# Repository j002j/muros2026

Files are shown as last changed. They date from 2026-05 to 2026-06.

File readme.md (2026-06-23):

# Ocean Oxygen Physicalisation

<p align="center">
  Titelbild
</p>

An interactive physical computing installation that visualises dissolved oxygen patterns in ocean Oxygen Minimum Zones (OMZs) through light, depth and material.

The installation uses an ESP32, a 289 LED NeoPixel matrix, five physical buttons and five stacked milky acrylic layers. Instead of showing the dataset on a screen, oxygen values are translated into a spatial light object. Each acrylic layer represents a depth zone, while each button selects a different year.

The project focuses on two ocean regions:

- **Peru-Chile Oxygen Minimum Zone**
- **Eastern Tropical Atlantic Oxygen Minimum Zone**

Both regions are used as case studies for communicating ocean deoxygenation, marine stress and the fragile visual language of oxygen loss.

---

## Project Idea

Oxygen Minimum Zones are ocean regions where dissolved oxygen is very low. They are natural features of the ocean, but ocean warming and climate-driven changes can intensify deoxygenation and affect marine ecosystems.

This installation turns that abstract phenomenon into a physical experience.

The visual system follows a **“Bleached Ocean” / “Cyan Stress”** aesthetic:

- deep blue = oxygen-rich / stable
- cyan = stressed transition state
- pale bleached tones = oxygen-depleted / fragile
- layered acrylic = ocean depth
- soft diffusion = underwater atmosphere

The goal is not to create a precise scientific chart, but a data-based physical interpretation that makes oxygen loss emotionally readable.

---

## Interaction

The installation has five physical buttons.

| Button | Year |
|---|---|
| Button 1 | 2004 |
| Button 2 | 2009 |
| Button 3 | 2014 |
| Button 4 | 2019 |
| Button 5 | 2024 |

Pressing a button changes the displayed year.  
The LED matrix fades into the selected data state instead of switching abruptly.

Additional interaction modes:

| Interaction | Function |
|---|---|
| Short button press | Select year |
| Hold Button 2 | Switch installation on/off |
| Hold Button 5 | Start/stop Auto-Play |
| Idle mode | Subtle ocean breathing |
| Auto-Play | Automatically moves through the years |

The interaction is intentionally simple: the object should feel like a calm ocean artefact, not like a technical control panel.

---

## Visual Mapping

The installation maps oxygen conditions to a custom colour palette.

```python
O2_PALETTE = [
    (140, 135, 110), # Step 0: bleached / oxygen-depleted
    (0, 255, 180),   # Step 1: stressed cyan
    (0, 100, 200),   # Step 2: cyan-blue
    (0, 0, 120),     # Step 3: dark royal blue
    (0, 0, 200),     # Step 4: saturated blue
    (0, 0, 255)      # Step 5: deep ocean blue
]
```

The mapping is intentionally atmospheric, but still data-based.
It is designed to make later years appear more stressed, pale and fragile where oxygen decreases.

## Regions
Peru-Chile OMZ

The Peru-Chile OMZ is used as one of the main visual scenarios.
It represents a strong oxygen minimum zone in the eastern tropical Pacific and is especially suitable for a dramatic visual story because oxygen depletion can be spatially intense.

In the installation, this region is mapped across five depth layers and five selected years.

Eastern Tropical Atlantic OMZ

The Eastern Tropical Atlantic region is included as a second ocean case study.
It allows comparison between different oxygen minimum zone dynamics and helps communicate that ocean deoxygenation is not a single local event, but part of a broader marine pattern.

The code can be adapted to switch between the two regional mappings.

## Hardware

Main components:

Component	Description
Microcontroller	ESP32
LEDs	NeoPixel / WS2812 matrix
LED count	289 LEDs
Interaction	5 physical push buttons
Material	5 milky acrylic layers
Power	External 5V LED power supply
Pin Configuration
Component	ESP32 Pin
LED data pin	GPIO 13
Button 1	GPIO 19
Button 2	GPIO 18
Button 3	GPIO 5
Button 4	GPIO 17
Button 5	GPIO 16

The buttons use internal pull-up resistors and are active-low.
This means that pressing a button connects the GPIO pin to GND.

## Software

The installation is written in MicroPython and runs directly on the ESP32.

Recommended editor:

Thonny

Main libraries:

```python
from machine import Pin
from neopixel import NeoPixel
from time import sleep_ms, ticks_ms, ticks_diff
import math
```
MicroPython usually includes NeoPixel support by default.
If needed, the NeoPixel package can be installed through Thonny’s package manager.

## Inspiration

Brainstorming and visual research:
https://www.figma.com/board/NZpllUfHZYUcmpAbdbsu1X/Morus2026

## Sources and References

Scientific and data references:

NOAA Ocean Exploration
https://oceanexplorer.noaa.gov/ocean-fact/omz/

NOAA National Centers for Environmental Information, World Ocean Atlas
https://www.ncei.noaa.gov/products/world-ocean-atlas

World Ocean Atlas 2023 Data
https://www.ncei.noaa.gov/access/world-ocean-atlas-2023/

Copernicus Marine, Global Ocean Biogeochemistry Hindcast
https://data.marine.copernicus.eu/product/GLOBAL_MULTIYEAR_BGC_001_029/description

Karstensen et al., Oxygen minimum zones in the eastern tropical Atlantic and Pacific oceans
https://oceanrep.geomar.de/7187/

Technical references:

MicroPython
https://micropython.org/

Thonny Python IDE
https://thonny.org/

Adafruit NeoPixel Überguide
https://learn.adafruit.com/adafruit-neopixel-uberguide

## Credits

Created as part of a data physicalisation project on ocean oxygen decline and marine stress.

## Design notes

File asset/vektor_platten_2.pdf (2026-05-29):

Durchmesser 184

Material: Plexiglass 2mm dick

Bearbeitung mit Laserzuschnitt

Toleranz: ±0,3 mm ?????

Bohrung: Keine

Alle alle 3 mm

Erste Ebene

- 184 cm durchmesser
- Diese Schicht dient als Diffusor, damit die LEDs dadrunter weich gemahct werden.
- Es soll leich milchig sein (damit die LEDs under der platte sanfter durchleuchten)
- Um das milchige zu erhlaten, die oberfläche anrauen oder so

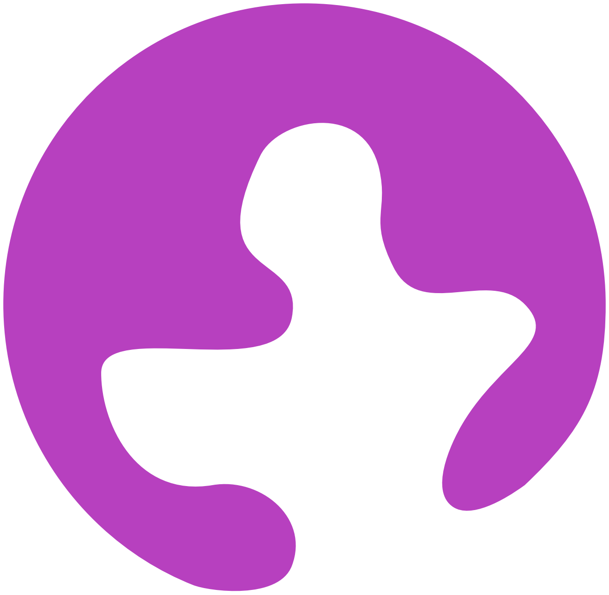
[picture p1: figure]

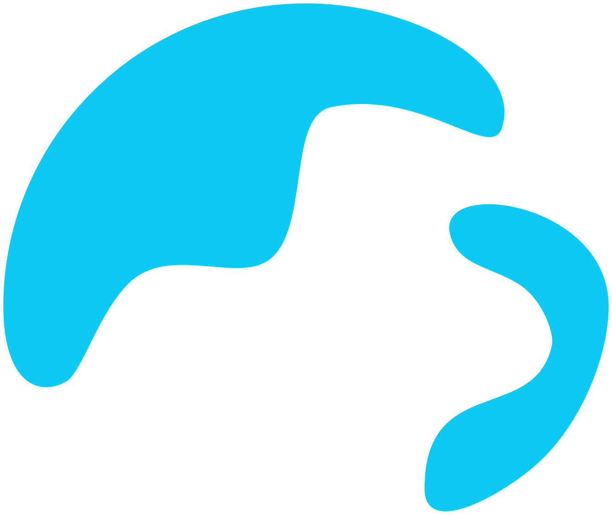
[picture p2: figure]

Die Platten sollen am Ende überinandergelagert werden.

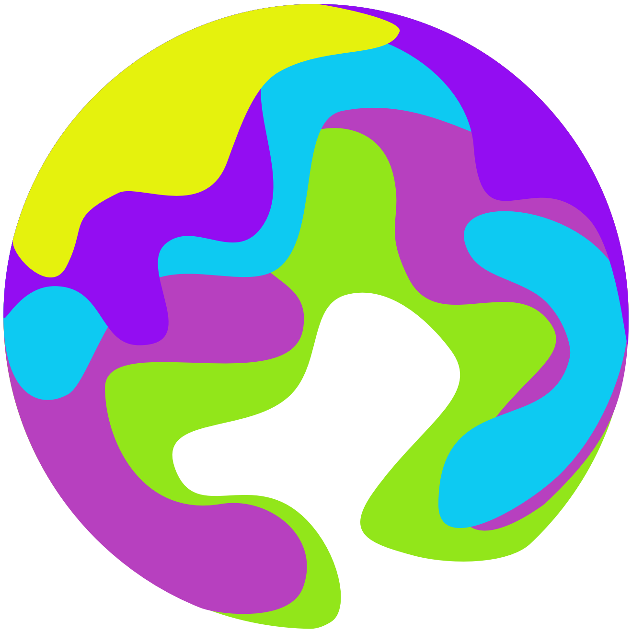
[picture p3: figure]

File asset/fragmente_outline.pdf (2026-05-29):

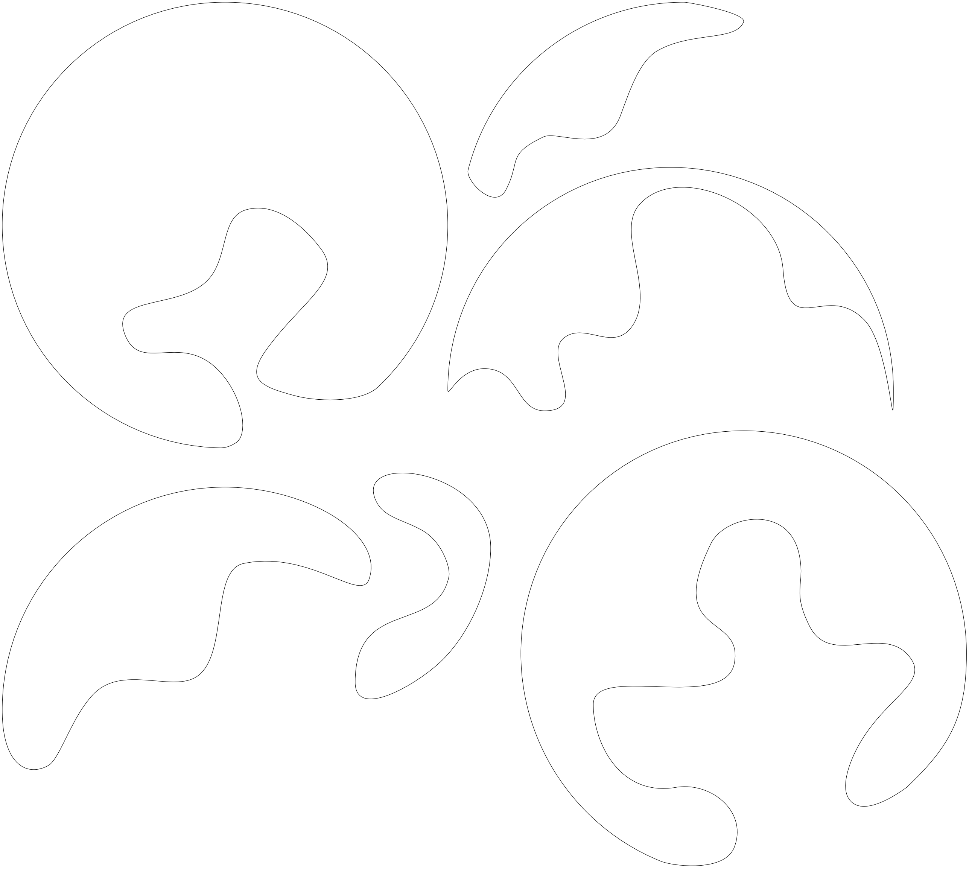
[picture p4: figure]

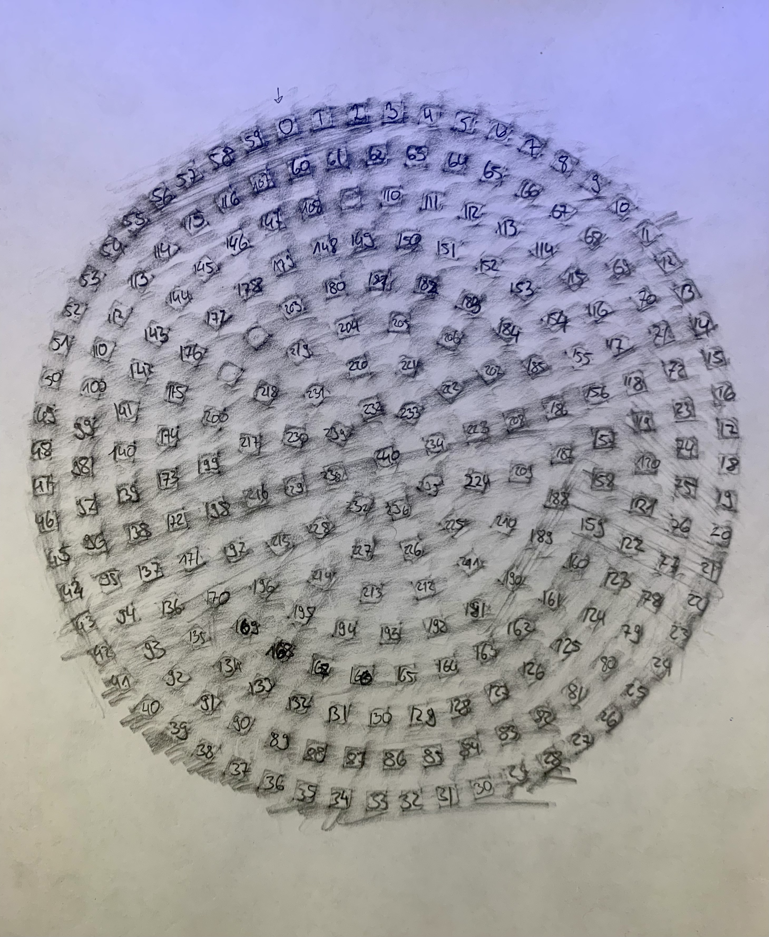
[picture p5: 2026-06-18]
asset/led_ numbered.jpeg

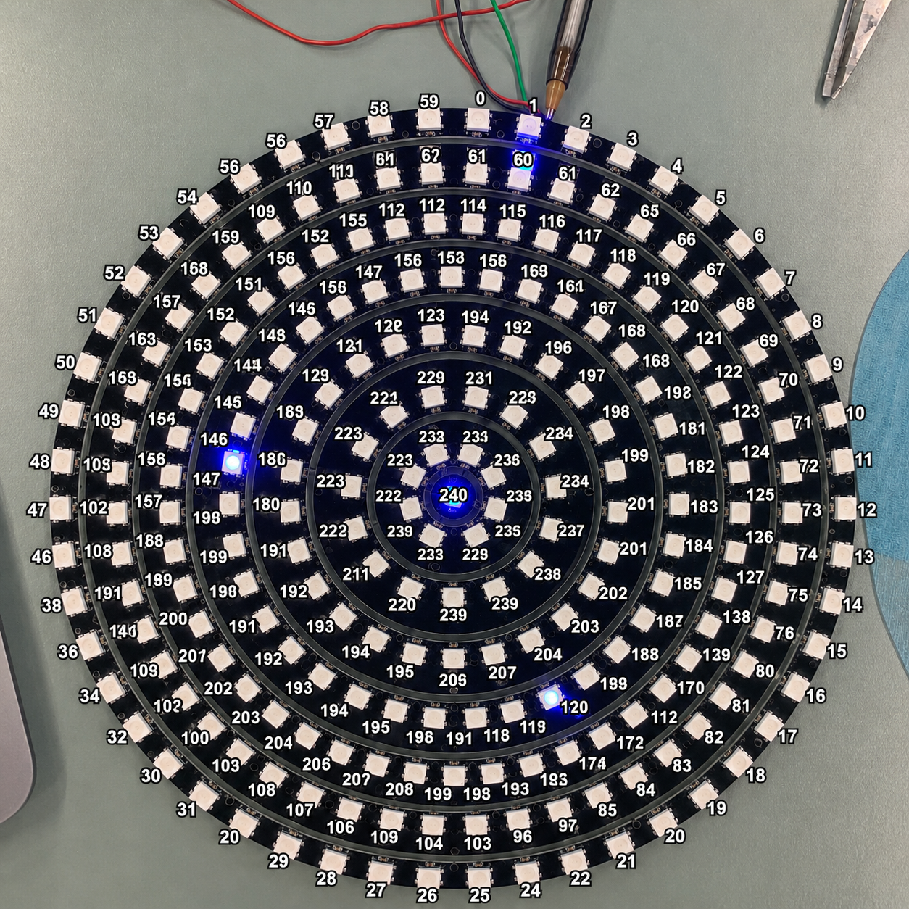
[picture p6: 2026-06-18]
asset/led_falsely_numberd.png

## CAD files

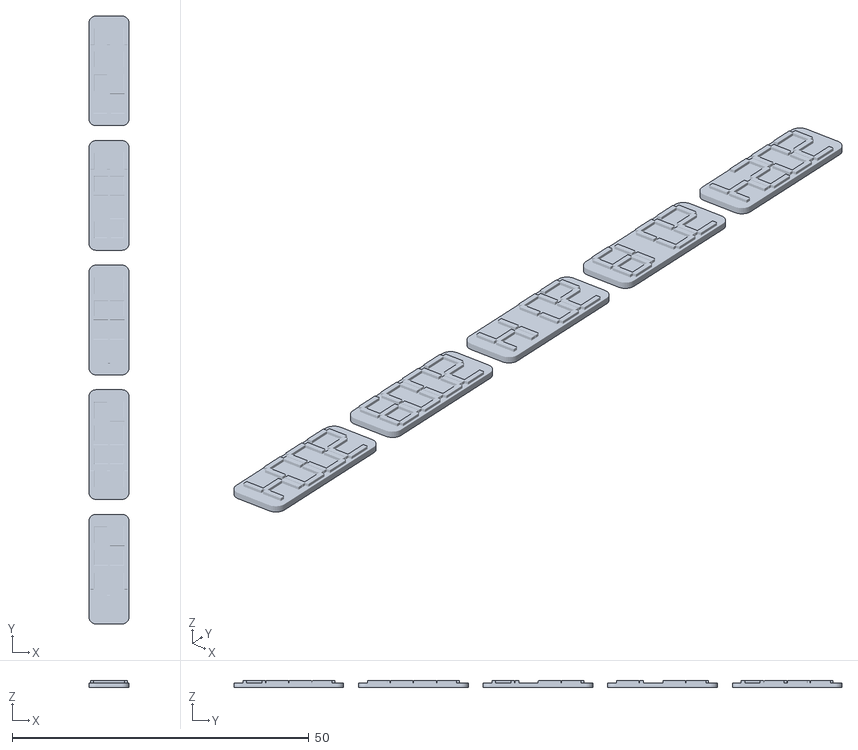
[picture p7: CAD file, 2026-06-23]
finalversion/jahresschilder.stl
6.80 x 102.5 x 1.10

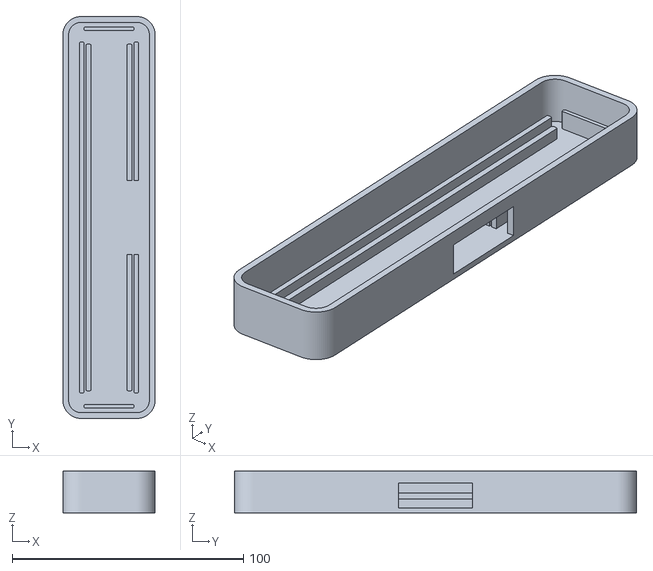
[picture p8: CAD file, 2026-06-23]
finalversion/unterteil.stl
40.0 x 174.0 x 18.0

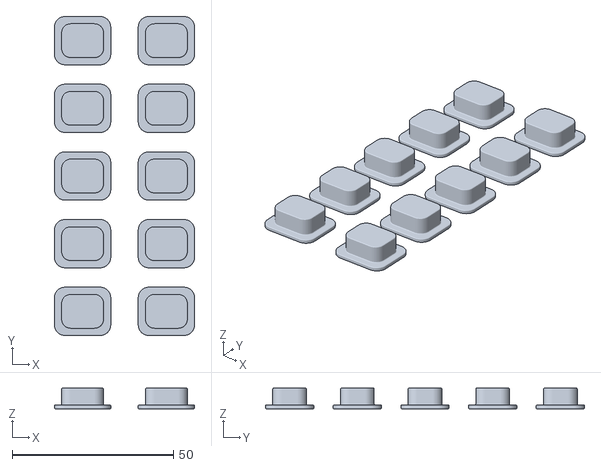
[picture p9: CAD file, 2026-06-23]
finalversion/knopfvarianten.stl
43.5 x 99.0 x 6.40

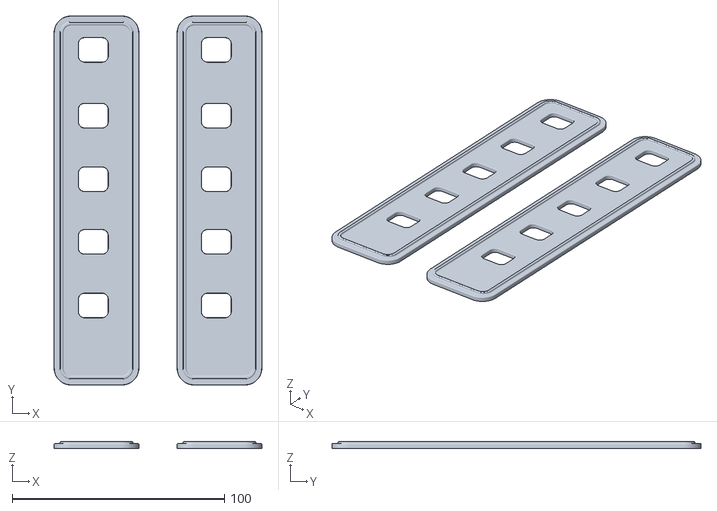
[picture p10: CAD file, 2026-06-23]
finalversion/deckel.stl
98.0 x 174.0 x 3.40

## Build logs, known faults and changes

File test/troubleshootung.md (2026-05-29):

```markdown
# Problembehebung: ESP32 "Device is busy" & Thonny Absturz auf macOS

## 1. Das ursprüngliche Problem
Beim Versuch, den ESP32 mit der IDE **Thonny** auf dem Mac anzusteuern, erschien folgende Fehlermeldung:
> *Device is busy or does not respond. Your options: wait until it completes current work; use Ctrl+C to interrupt current work...*

Zusätzlich stürzte das eingebaute MicroPython-Flash-Werkzeug von Thonny mit einem Python-Fehler ab:
`AttributeError: 'NoneType' object has no attribute 'port'`

### Ursachen-Analyse:
1. **Kein MicroPython auf dem Board:** Der ESP32 wurde im Werkszustand geliefert (meistens mit C++ Firmware) und verstand Thonny nicht.
2. **Thonny-Software-Bug:** Ein bekannter Fehler im Zusammenspiel zwischen Thonny, macOS und Python 3.14 verhinderte, dass Thonny den USB-Port korrekt zuordnen und die Firmware flashen konnte.
3. **Anaconda-Konflikt:** Auf dem Mac ist Anaconda installiert, weshalb Standard-Terminalbefehle wie `pip` oder `python3` in die Anaconda-Umgebung umgeleitet wurden, wo das Flash-Werkzeug (`esptool`) fehlte.

---

## 2. Der Lösungsansatz
Da die grafische Oberfläche von Thonny blockiert war, wurde die Installation von MicroPython komplett an Thonny vorbei über das native **macOS-Terminal** durchgeführt. Dabei wurde das offizielle Espressif-Flash-Werkzeug (`esptool`) direkt über den spezifischen Anaconda-Pfad installiert und ausgeführt.

---

## 3. Konkreter Lösungsweg (Schritt für Schritt)

### Schritt 1: Thonny schließen
Thonny vollständig beenden (`Cmd + Q`), damit die USB-Verbindung zum ESP32 nicht blockiert wird.

### Schritt 2: Den USB-Port des ESP32 ermitteln
Das macOS-Terminal öffnen und alle aktiven USB-Schnittstellen auflisten:
```bash
ls /dev/cu.*

```

*Ergebnis:* Der korrekte Port wurde als **`/dev/cu.usbserial-1410`** identifiziert (da der verbaute CP2102N-Chip korrekt vom Mac erkannt wurde).

### Schritt 3: Flash-Tool in der Anaconda-Umgebung installieren

Da Anaconda als Standard-Python genutzt wird, musste das Tool über den absoluten Anaconda-Pfad installiert werden:

```bash
/opt/anaconda3/bin/pip install esptool

```

### Schritt 4: Alten Flash-Speicher des ESP32 löschen

Um Reste alter Firmware zu entfernen, wurde der Speicher geleert:

```bash
/opt/anaconda3/bin/python3 -m esptool --port /dev/cu.usbserial-1410 erase_flash

```

*Hinweis:* Sobald im Terminal `Connecting...` erscheint, muss der **BOOT-Knopf** auf dem ESP32 gedrückt gehalten werden.

### Schritt 5: MicroPython-Firmware aufspielen

Die aktuelle MicroPython `.bin`-Datei (z. B. `v1.28.0.bin`) von der offiziellen Website herunterladen. Den Befehl im Terminal vorbereiten, ein Leerzeichen tippen und die Datei per Drag & Drop in das Terminal ziehen:

```bash
/opt/anaconda3/bin/python3 -m esptool --chip esp32 --port /dev/cu.usbserial-1410 write_flash -z 0x1000 /Pfad/zur/heruntergeladenen/datei.bin

```

*Hinweis:* Auch hier bei `Connecting...` den **BOOT-Knopf** am ESP32 gedrückt halten, bis der Upload startet (Prozentanzeige läuft bis 100%).

---

## 4. Ergebnis & Nächste Schritte

Nachdem `Hash of data verified.` im Terminal stand, wurde der ESP32 erfolgreich geflasht.

**Vorgehen jetzt in Thonny:**

1. ESP32 einmal kurz vom USB-Kabel trennen und wieder anstecken.
2. Thonny öffnen.
3. Unter *Werkzeuge -> Optionen -> Interpreter* als Gerät **MicroPython (ESP32)** und als Port explizit **`/dev/cu.usbserial-1410`** auswählen.
4. Den roten **Stop-Button** in Thonny drücken.
5. In der Shell erscheinen die drei Pfeile (`>>>`) – der ESP32 ist nun einsatzbereit für die LED-Steuerung.

## Wenn der Fehler nochmal vorkommt
```bash
ls /dev/cu.*
```

die ausgaben oben in das XXX unten einsetzten:

```bash
/opt/anaconda3/bin/python3 -m esptool --port /dev/cu.XXX erase_flash
```
Da die .bin-Datei wahrscheinlich noch in deinem Download-Ordner ist, musst diese nur wieder reingeschoben werden. Befehl eintippen, Leerzeichen, Datei per Drag & Drop reinziehen (und wieder den BOOT-Knopf drücken):

```bash
/opt/anaconda3/bin/python3 -m esptool --chip esp32 --port /dev/cu.usbserial-1410 write_flash -z 0x1000 /Pfad/zur/heruntergeladenen/datei.bin
```

```

```

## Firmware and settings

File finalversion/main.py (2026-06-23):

# main.py
# ESP32 + MicroPython + NeoPixel/WS2812
# Ocean O2 Data Physicalisation
# Edition: "Cyan Stress" + Flowy Auto-Play & Subtles Feedback

from machine import Pin
from neopixel import NeoPixel
from time import sleep_ms, ticks_ms, ticks_diff
import math

# =======================================================
# 1. HARDWARE-KONFIGURATION
# =======================================================

LED_PIN = 13
NUM_LEDS = 289  # Volle Matrix

BUTTON_PINS = [19, 18, 5, 17, 16]
BUTTON_ACTIVE_VALUE = 0
BUTTON_PULL = Pin.PULL_UP
BRIGHTNESS = 1.0

# =======================================================
# 2. ZONEN & AUTO-FILL
# =======================================================

BOTTOM_LAYER = [
    28, 29, 30, 31, 32, 84, 85, 86, 129, 130, 165, 166, 167, 168, 169,
    181, 191, 192, 193, 194, 195, 210, 211, 212, 213, 214, 224, 225,
    226, 227, 235, 236
]

ZONE_RANGES = [
    [14, 15, 26, 27, 33, 34, 82, 83, 86, 127, 128, 130, 121, 158, 159, 160, 161, 162, 163, 164, 134, 135, 136, 137, 138, 170, 171, 197, 196, 215, 228, 237, 240, 234, 209, 223, 222, 233, 232, 224, 205, 206, 181, 182],
    [122, 131, 132, 133, 87, 88, 89, 90, 91, 92, 93, 94, 95, 35, 36, 37, 38, 39, 40, 41, 42, 43, 44, 45, 138, 198, 216, 229, 238, 217, 230, 239, 150, 151, 152, 153, 154, 184, 183, 185, 207, 208, 187, 172, 117, 204],
    [126, 162, 231, 220, 204, 180, 181, 96, 97, 98, 156, 147, 139, 140, 218, 200, 149, 148, 109, 110, 111, 112, 113, 114, 81, 80, 79, 77, 76, 75, 74, 73, 120, 119, 118, 20, 19, 18],
    [19, 18, 17, 16, 15, 14, 13, 12, 11, 10, 69, 70, 71, 72, 115, 116, 65, 66, 67, 68, 173, 174, 175, 176, 141, 142, 143, 99, 48, 49, 219, 203],
    [177, 178, 179, 144, 145, 146, 147, 105, 61, 60, 0, 1, 2, 3, 4, 5, 50, 51, 52, 53, 54, 56, 57, 58, 59, 100, 101, 102, 103, 104, 106, 107, 108]
]

mapped_leds = set(BOTTOM_LAYER)
for layer in ZONE_RANGES:
    mapped_leds.update(layer)
unmapped_leds = [i for i in range(NUM_LEDS) if i not in mapped_leds]
BOTTOM_LAYER.extend(unmapped_leds)

# =======================================================
# 3. DATA MAPPING 
# =======================================================

YEARS = [2004, 2009, 2014, 2019, 2024]

AMBIENT_COLOR = (0, 0, 8)       
BOTTOM_COLOR = (0, 0, 15)       

O2_PALETTE = [
    (140, 135, 110), # Step 0: Knochenweiß (Tot)
    (0, 255, 180),   # Step 1: Grelles Cyan (Warnung)
    (0, 100, 200),   # Step 2: Cyan-Blau 
    (0, 0, 120),     # Step 3: Dunkles Royalblau 
    (0, 0, 200),     # Step 4: Sattes Royalblau
    (0, 0, 255)      # Step 5: Pures, tiefes Royalblau 
]

OMZ_DATA_STEPS = [
    [5, 4, 1, 4, 5], # 2004
    [5, 3, 0, 3, 5], # 2009
    [4, 1, 0, 1, 4], # 2014
    [3, 0, 0, 0, 2], # 2019
    [1, 0, 0, 0, 2], # 2024
]

LAYER_COMPENSATION = [1.0, 1.0, 1.0, 1.0, 1.0]

# =======================================================
# 4. GLOBALE STATUS-VARIABLEN FÜR ANIMATIONEN
# =======================================================

base_pixels = [(0,0,0)] * NUM_LEDS
is_dead_pixel = [False] * NUM_LEDS  
current_year_index = 0

# =======================================================
# 5. SETUP & HELPERS
# =======================================================

np = NeoPixel(Pin(LED_PIN, Pin.OUT), NUM_LEDS)
buttons = [Pin(pin_number, Pin.IN, BUTTON_PULL) for pin_number in BUTTON_PINS]

def scale_color(color, comp_factor=1.0):
    r, g, b = color
    return (int(r * BRIGHTNESS * comp_factor), int(g * BRIGHTNESS * comp_factor), int(b * BRIGHTNESS * comp_factor))

def clear_leds():
    for i in range(NUM_LEDS):
        np[i] = (0, 0, 0)
    np.write()

def build_target_data(year_index):
    t_pixels = [scale_color(AMBIENT_COLOR)] * NUM_LEDS
    t_dead = [False] * NUM_LEDS

    bottom_scaled = scale_color(BOTTOM_COLOR)
    for led_idx in BOTTOM_LAYER:
        if 0 <= led_idx < NUM_LEDS:
            t_pixels[led_idx] = bottom_scaled

    for layer_index in range(5):
        step = OMZ_DATA_STEPS[year_index][layer_index]
        comp = LAYER_COMPENSATION[layer_index]
        layer_color = scale_color(O2_PALETTE[step], comp_factor=comp)
        
        is_dead = (step == 0) 

        for led_idx in ZONE_RANGES[layer_index]:
            if 0 <= led_idx < NUM_LEDS:
                t_pixels[led_idx] = layer_color
                t_dead[led_idx] = is_dead

    return t_pixels, t_dead

# =======================================================
# 6. GIMMICKS: FEEDBACK + BREATHING
# =======================================================

FEEDBACK_EDGE_COLOR = (0, 28, 55)  
FEEDBACK_EDGE_MS = 55            
FEEDBACK_EDGE_BLEND = 0.55        


# Atmen: .
BREATH_SPEED = 1400
BREATH_BASE = 0.97
BREATH_AMOUNT = 0.03

# Fade-Geschwindigkeiten:
BUTTON_FADE_STEPS = 18
BUTTON_FADE_DELAY_MS = 12

AUTOPLAY_FADE_STEPS = 64
AUTOPLAY_FADE_DELAY_MS = 18

POWER_FADE_STEPS = 18
POWER_FADE_DELAY_MS = 10

def get_data_leds():
    """
    Nur die 5 echten Daten-Zonen.
    Bottom, Rand und Auto-Fill gehören NICHT dazu.
    """
    data = set()

    for layer in ZONE_RANGES:
        for led in layer:
            if 0 <= led < NUM_LEDS:
                data.add(led)

    return data


DATA_LEDS = get_data_leds()
FEEDBACK_LEDS = [i for i in range(NUM_LEDS) if i not in DATA_LEDS]


def feedback_kick(restore_after=True):
    """
    Data-neutrales Button-Feedback:
    Nur Rand-/Nicht-Daten-LEDs bekommen kurz einen kühlen Impuls.
    Die eigentlichen Datenzonen bleiben unverändert.
    """
    start_pixels = [np[i] for i in range(NUM_LEDS)]
    fc = scale_color(FEEDBACK_EDGE_COLOR)

    for led in FEEDBACK_LEDS:
        r, g, b = start_pixels[led]

        np[led] = (
            int(r * (1 - FEEDBACK_EDGE_BLEND) + fc[0] * FEEDBACK_EDGE_BLEND),
            int(g * (1 - FEEDBACK_EDGE_BLEND) + fc[1] * FEEDBACK_EDGE_BLEND),
            int(b * (1 - FEEDBACK_EDGE_BLEND) + fc[2] * FEEDBACK_EDGE_BLEND)
        )

    np.write()
    sleep_ms(FEEDBACK_EDGE_MS)

    if restore_after:
        for led in FEEDBACK_LEDS:
            np[led] = start_pixels[led]

        np.write()

def get_breath_factor():
    return BREATH_BASE + BREATH_AMOUNT * math.sin(ticks_ms() / BREATH_SPEED)


def apply_breath_to_color(color, factor):
    r, g, b = color
    return (
        int(r * factor),
        int(g * factor),
        int(b * factor)
    ) 

def render_ocean_breath():
    """
    subtiler Ocean Breath.
    Nur die echten Datenlayer atmen.
    Boden, Rand und Auto-Fill bleiben konstant.
    """
    factor = get_breath_factor()

    for i in range(NUM_LEDS):
        np[i] = base_pixels[i]

    for i in DATA_LEDS:
        r, g, b = base_pixels[i]
        np[i] = (
            int(r * factor),
            int(g * factor),
            int(b * factor)
        )

    np.write()


# =======================================================
# 7. DISPLAY & FADE LOGIC
# =======================================================

def show_year(year_index):
    global current_year_index, base_pixels, is_dead_pixel

    current_year_index = year_index
    base_pixels, is_dead_pixel = build_target_data(year_index)

    for i in range(NUM_LEDS):
        np[i] = base_pixels[i]

    np.write()

    print("AKTIV:", YEARS[year_index])
    for layer_index in range(5):
        step = OMZ_DATA_STEPS[year_index][layer_index]
        comp = LAYER_COMPENSATION[layer_index]
        rgb = scale_color(O2_PALETTE[step], comp)
        print("  Layer", layer_index + 1, "| Step", step, "| RGB", rgb)


def fade_to_year(year_index, steps=BUTTON_FADE_STEPS, delay_ms=BUTTON_FADE_DELAY_MS):
    """
    Weicher Fade zum Zieljahr.
    Buttondruck = zügig.
    Auto-Play = langsamer über andere Parameter.
    """
    global current_year_index, base_pixels, is_dead_pixel

    start_pixels = [np[i] for i in range(NUM_LEDS)]
    target_pixels, target_dead = build_target_data(year_index)

    for step in range(1, steps + 1):
        t = step / steps

        t = t * t * (3 - 2 * t)

        # Zielbild schon in der aktuellen Breath-Helligkeit berechnen
        breath_factor = get_breath_factor()

        for i in range(NUM_LEDS):
            sr, sg, sb = start_pixels[i]

            tr, tg, tb = apply_breath_to_color(target_pixels[i], breath_factor)

            np[i] = (
                int(sr + (tr - sr) * t),
                int(sg + (tg - sg) * t),
                int(sb + (tb - sb) * t)
            )

        np.write()
        sleep_ms(delay_ms)

    current_year_index = year_index
    base_pixels = target_pixels
    is_dead_pixel = target_dead

    render_ocean_breath()

    print("GEWECHSELT ZU:", YEARS[year_index])
    for layer_index in range(5):
        step = OMZ_DATA_STEPS[year_index][layer_index]
        comp = LAYER_COMPENSATION[layer_index]
        rgb = scale_color(O2_PALETTE[step], comp)
        print("  Layer", layer_index + 1, "| Step", step, "| RGB", rgb)


def fade_to_black(steps=POWER_FADE_STEPS, delay_ms=POWER_FADE_DELAY_MS):
    """
    Sanftes Ausschalten, ohne den MicroPython-Stack zu killen.
    Der Code läuft weiter, LEDs gehen nur optisch aus.
    """
    global base_pixels, is_dead_pixel

    start_pixels = [np[i] for i in range(NUM_LEDS)]

    for step in range(1, steps + 1):
        t = step / steps
        t = t * t * (3 - 2 * t)

        for i in range(NUM_LEDS):
            sr, sg, sb = start_pixels[i]
            np[i] = (
                int(sr * (1 - t)),
                int(sg * (1 - t)),
                int(sb * (1 - t))
            )

        np.write()
        sleep_ms(delay_ms)

    clear_leds()
    base_pixels = [(0, 0, 0)] * NUM_LEDS
    is_dead_pixel = [False] * NUM_LEDS

# =======================================================
# 8. BUTTON CONTROLS
# =======================================================

def read_buttons():
    for idx, button in enumerate(buttons):
        if button.value() == BUTTON_ACTIVE_VALUE:
            sleep_ms(40) 
            if button.value() == BUTTON_ACTIVE_VALUE:
                return idx
    return None

def wait_until_released(button_index):
    while buttons[button_index].value() == BUTTON_ACTIVE_VALUE:
        sleep_ms(20)

# =======================================================
# 9. START & MAIN LOOP
# =======================================================

clear_leds()
show_year(0)

is_system_on = True
auto_play_active = False

POWER_BUTTON_INDEX = 1       
POWER_HOLD_MS = 2000         

AUTOPLAY_BUTTON_INDEX = 4    
AUTOPLAY_HOLD_MS = 5000         

last_interaction_time = ticks_ms()
last_auto_switch = ticks_ms()

AUTO_PLAY_INTERVAL = 8000
ATTRACT_MODE_DELAY = 120000

print("SYSTEM BEREIT.")
print("Button 2 / 2009 kurz: Jahr 2009.")
print("Button 2 / 2009 halten: AN/AUS.")
print("Button 5 / 2024 halten: Auto-Play AN/AUS.")
print("Breathing: nur Datenlayer, Boden/Rand stabil.")


while True:
    current_time = ticks_ms()
    pressed = read_buttons()

    # ===================================================
    # BUTTON GEDRÜCKT
    # ===================================================
    if pressed is not None:
        press_start = ticks_ms()
        hold_done = False

        # -----------------------------------------------
        # BUTTON 2 HOLD: SYSTEM AN/AUS
        # -----------------------------------------------
        if pressed == POWER_BUTTON_INDEX:
            while buttons[POWER_BUTTON_INDEX].value() == BUTTON_ACTIVE_VALUE:
                held_ms = ticks_diff(ticks_ms(), press_start)

                if is_system_on:
                    render_ocean_breath()

                if held_ms >= POWER_HOLD_MS:
                    is_system_on = not is_system_on
                    auto_play_active = False
                    hold_done = True

                    last_interaction_time = ticks_ms()
                    last_auto_switch = ticks_ms()

                    if is_system_on:
                        print("SYSTEM: ON")
                        show_year(current_year_index)
                        feedback_kick(restore_after=True)
                    else:
                        print("SYSTEM: OFF")
                        feedback_kick(restore_after=True)
                        fade_to_black()

                    # warten, bis Button losgelassen wird
                    while buttons[POWER_BUTTON_INDEX].value() == BUTTON_ACTIVE_VALUE:
                        sleep_ms(20)

                    break

                sleep_ms(20)

            if hold_done:
                continue

        # -----------------------------------------------
        # BUTTON 5 HOLD: AUTO-PLAY AN/AUS
        # -----------------------------------------------
        if pressed == AUTOPLAY_BUTTON_INDEX and is_system_on:
            while buttons[AUTOPLAY_BUTTON_INDEX].value() == BUTTON_ACTIVE_VALUE:
                held_ms = ticks_diff(ticks_ms(), press_start)

                render_ocean_breath()

                if held_ms >= AUTOPLAY_HOLD_MS:
                    auto_play_active = not auto_play_active
                    hold_done = True

                    last_interaction_time = ticks_ms()
                    last_auto_switch = ticks_ms()

                    if auto_play_active:
                        print("AUTO-PLAY: ON")
                    else:
                        print("AUTO-PLAY: OFF")

                    feedback_kick(restore_after=True)

                    while buttons[AUTOPLAY_BUTTON_INDEX].value() == BUTTON_ACTIVE_VALUE:
                        sleep_ms(20)

                    break

                sleep_ms(20)

            if hold_done:
                continue

        # -----------------------------------------------
        # NORMALER KURZER BUTTON-KLICK
        # -----------------------------------------------
        wait_until_released(pressed)

        current_time = ticks_ms()
        last_interaction_time = current_time
        last_auto_switch = current_time

        if not is_system_on:
            continue

        if auto_play_active:
            auto_play_active = False
            print("AUTO-PLAY: OFF durch manuelle Eingabe")

        print("Button erkannt:", pressed + 1, "| Jahr:", YEARS[pressed])

        if pressed != current_year_index:
            feedback_kick(restore_after=True)
            fade_to_year(
                pressed,
                steps=BUTTON_FADE_STEPS,
                delay_ms=BUTTON_FADE_DELAY_MS
            )
        else:
            feedback_kick(restore_after=True)

        last_auto_switch = ticks_ms()

    # ===================================================
    # IDLE / AUTO-PLAY
    # ===================================================
    if is_system_on:
        render_ocean_breath()

        idle_time = ticks_diff(current_time, last_interaction_time)
        attract_mode_active = idle_time > ATTRACT_MODE_DELAY

        if auto_play_active or attract_mode_active:
            if ticks_diff(current_time, last_auto_switch) > AUTO_PLAY_INTERVAL:
                next_year = (current_year_index + 1) % len(YEARS)

                if auto_play_active:
                    print("AUTO-PLAY:", YEARS[next_year])
                else:
                    print("ATTRACT-MODE:", YEARS[next_year])

                fade_to_year(
                    next_year,
                    steps=AUTOPLAY_FADE_STEPS,
                    delay_ms=AUTOPLAY_FADE_DELAY_MS
                )

                last_auto_switch = ticks_ms()

    else:
        sleep_ms(20)

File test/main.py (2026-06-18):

# main.py
# ESP32 + MicroPython + NeoPixel/WS2812
# Ocean O2 Data Physicalisation
# 5 Buttons = 5 Jahre
# 5 Plexiglas-Layer = 5 Tiefenzonen
#
# Neue Version:
# - Layer-Unterschiede werden durch stärkere Farbpalette sichtbar.
# - Jahres-Unterschiede werden durch leichten Year-Tint sichtbar.
# - Bottom-Layer wird zuerst gezeichnet, Datenlayer danach.

from machine import Pin
from neopixel import NeoPixel
from time import sleep_ms

# =======================================================
# 1. HARDWARE-KONFIGURATION
# =======================================================

LED_PIN = 13
NUM_LEDS = 241

# Button-Pins von GND aus nach links:
# Button 1 = 2004
# Button 2 = 2009
# Button 3 = 2014
# Button 4 = 2019
# Button 5 = 2024
BUTTON_PINS = [19, 18, 5, 17, 16]

# Annahme: Button verbindet GPIO mit GND.
# gedrückt = 0, nicht gedrückt = 1
BUTTON_ACTIVE_VALUE = 0
BUTTON_PULL = Pin.PULL_UP

# Globaler Helligkeitsregler:
# 1.0 = volle Werte
# 0.7 = etwas softer
# 0.5 = deutlich weicher
BRIGHTNESS = 0.8

# Fade an/aus
USE_FADE = True

# Bottom-Layer / Basislicht
WEISS = (20, 20, 20)

BOTTOM_LAYER = [ 28, 29, 30, 31, 32, 84, 85, 86, 129, 130, 165, 166, 167, 168, 169, 181, 191, 192, 193, 194, 195, 210, 211, 212, 213, 214, 224, 225, 226, 227, 235, 236 ] # Die verbleibenden 209 Daten-LEDs – jede Zahl existiert exakt 1x!
ZONE_RANGES = [
    # Layer 1: 100-250m (45 LEDs -> Doppelte 126 bereinigt, Lücken geschlossen)
    [14, 15, 26, 27, 33, 34, 82, 83, 121, 123, 124, 125, 127, 128, 134, 135, 136, 137, 138, 158, 159, 160, 161, 162, 163, 164, 170, 171, 182, 186, 196, 197, 199, 205, 206, 209, 215, 221, 222, 223, 228, 232, 233, 234, 237, 240],
    # Layer 2: 250-400m (53 LEDs)
    [35, 36, 37, 38, 39, 40, 41, 42, 43, 44, 45, 87, 88, 89, 90, 91, 92, 93, 94, 95, 117, 122, 131, 132, 133, 150, 151, 152, 153, 154, 155, 172, 183, 184, 185, 187, 188, 189, 190, 198, 201, 202, 203, 204, 207, 208, 216, 217, 229, 230, 231, 238, 239],
    # Layer 3: 400-600m (36 LEDs)
    [18, 19, 20, 21, 22, 23, 24, 25, 73, 74, 75, 76, 77, 79, 80, 81, 96, 97, 98, 109, 110, 111, 112, 113, 114, 118, 119, 120, 126, 139, 140, 148, 149, 156, 180, 200, 218],
    # Layer 4: 600-750m (30 LEDs -> Doppelte Einträge am Ende entfernt)
    [6, 7, 8, 9, 10, 11, 12, 13, 16, 17, 48, 49, 65, 66, 67, 68, 69, 70, 71, 72, 99, 115, 116, 141, 142, 143, 173, 174, 175, 176, 219],
    # Layer 5: 750-900m (45 LEDs)
    [0, 1, 2, 3, 4, 5, 46, 47, 50, 51, 52, 53, 54, 55, 56, 57, 58, 59, 60, 61, 62, 63, 64, 78, 100, 101, 102, 103, 104, 105, 106, 107, 108, 144, 145, 146, 147, 177, 178, 179]
]

# =======================================================
# 2. DATA MAPPING V2
# =======================================================

YEARS = [2004, 2009, 2014, 2019, 2024]
LAYER_LABELS = ['100-250m', '250-400m', '400-600m', '600-750m', '750-900m']

# Eastern Tropical Atlantic | normal
# normal: more O2 = more blue
DATA_COLORS_EASTERN_TROPICAL_ATLANTIC_NORMAL = [
    [(0, 35, 148), (0, 14, 59), (0, 21, 90), (0, 44, 188), (0, 59, 251)],  # 2004
    [(0, 34, 144), (0, 14, 59), (0, 22, 94), (0, 45, 193), (0, 60, 255)],  # 2009
    [(0, 34, 146), (0, 14, 58), (0, 21, 90), (0, 44, 188), (0, 59, 250)],  # 2014
    [(0, 34, 144), (0, 13, 54), (0, 20, 87), (0, 43, 185), (0, 58, 246)],  # 2019
    [(0, 35, 147), (0, 12, 51), (0, 19, 79), (0, 42, 177), (0, 57, 243)],  # 2024
]

# Eastern Tropical Atlantic | inverted
# inverted: less O2 = more blue
DATA_COLORS_EASTERN_TROPICAL_ATLANTIC_INVERTED = [
    [(0, 37, 158), (0, 58, 247), (0, 51, 216), (0, 28, 118), (0, 13, 55)],  # 2004
    [(0, 38, 162), (0, 58, 247), (0, 50, 212), (0, 27, 113), (0, 12, 51)],  # 2009
    [(0, 38, 160), (0, 58, 248), (0, 51, 216), (0, 28, 118), (0, 13, 56)],  # 2014
    [(0, 38, 162), (0, 59, 252), (0, 52, 219), (0, 29, 121), (0, 14, 60)],  # 2019
    [(0, 37, 159), (0, 60, 255), (0, 53, 227), (0, 30, 129), (0, 15, 63)],  # 2024
]

# Peru-Chile OMZ / Eastern Tropical South Pacific | normal
# normal: more O2 = more blue
DATA_COLORS_PERU_CHILE_OMZ_NORMAL = [
    [(0, 56, 238), (0, 12, 51), (0, 13, 56), (0, 27, 116), (0, 39, 165)],  # 2004
    [(0, 55, 235), (0, 12, 51), (0, 13, 55), (0, 27, 113), (0, 39, 164)],  # 2009
    [(0, 54, 231), (0, 13, 53), (0, 14, 58), (0, 26, 112), (0, 38, 161)],  # 2014
    [(0, 56, 240), (0, 13, 55), (0, 14, 59), (0, 26, 112), (0, 38, 160)],  # 2019
    [(0, 60, 255), (0, 13, 55), (0, 15, 63), (0, 27, 113), (0, 38, 163)],  # 2024
]

# Peru-Chile OMZ / Eastern Tropical South Pacific | inverted
# inverted: less O2 = more blue
DATA_COLORS_PERU_CHILE_OMZ_INVERTED = [
    [(0, 16, 68), (0, 60, 255), (0, 59, 250), (0, 45, 190), (0, 33, 141)],  # 2004
    [(0, 17, 71), (0, 60, 255), (0, 59, 251), (0, 45, 193), (0, 33, 142)],  # 2009
    [(0, 18, 75), (0, 59, 253), (0, 58, 248), (0, 46, 194), (0, 34, 145)],  # 2014
    [(0, 16, 66), (0, 59, 251), (0, 58, 247), (0, 46, 194), (0, 34, 146)],  # 2019
    [(0, 12, 51), (0, 59, 251), (0, 57, 243), (0, 45, 193), (0, 34, 143)],  # 2024
]

DATASETS = {
    "m0": {
        "name": "Eastern Tropical Atlantic | normal | mehr O2 = mehr Blau",
        "colors": DATA_COLORS_EASTERN_TROPICAL_ATLANTIC_NORMAL
    },
    "m1": {
        "name": "Eastern Tropical Atlantic | inverted | weniger O2 = mehr Blau",
        "colors": DATA_COLORS_EASTERN_TROPICAL_ATLANTIC_INVERTED
    },
    "m2": {
        "name": "Peru-Chile OMZ | normal | mehr O2 = mehr Blau",
        "colors": DATA_COLORS_PERU_CHILE_OMZ_NORMAL
    },
    "m3": {
        "name": "Peru-Chile OMZ | inverted | weniger O2 = mehr Blau",
        "colors": DATA_COLORS_PERU_CHILE_OMZ_INVERTED
    },
}

# Startmodus:
# m2 = Peru-Chile OMZ normal
current_mode_key = "m2"
current_year_index = 0

# =======================================================
# 2b. VISUAL BOOST: LAYER-UNTERSCHIEDE + JAHRESUNTERSCHIEDE
# =======================================================

# Layer-Unterschiede stärker sichtbar machen
USE_COLOR_BOOST = True

# Kontrast für Layerunterschiede:
# 1.2 = sanft
# 1.8 = gut sichtbar
# 2.3 = stark
COLOR_CONTRAST = 6.0

# Jahres-Tint:
# Macht 2004 -> 2024 zusätzlich unterscheidbarer.
USE_YEAR_TINT = True

# Jahr 2004 bleibt heller/cyaniger,
# spätere Jahre werden leicht violetter/dunkler.
# Format: (add_red, add_green, add_blue)
YEAR_TINTS = [
    (0, 25, 35),      # 2004: heller/cyan
    (0, 12, 18),      # 2009
    (5, 0, 0),        # 2014 neutral/leicht violett
    (18, -10, -18),   # 2019
    (35, -22, -35),   # 2024: violetter/dunkler
]

# Optionaler Year-Dimming-Faktor:
# Verstärkt Jahresunterschiede zusätzlich.
# 2004 = 1.00, 2024 = 0.72
USE_YEAR_DIMMING = True
YEAR_DIM_FACTORS = [
    1.00,  # 2004
    0.93,  # 2009
    0.86,  # 2014
    0.78,  # 2019
    0.72,  # 2024
]
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

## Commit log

2026-05-28 make led blue
2026-05-29 mapped data
    [datamappingv4.csv]
2026-05-29 Update NUM_PIXELS to 241 in led.py
2026-05-29 inverted layer_ last version
    [test_layer_inverted.py]
2026-06-18 Update readme with Figma link and Thonny info
    Added a link to the Figma board and information about Thonny for programming LEDs.
2026-06-18 new folder structure
    [datamappingv4.csv]
2026-06-23 button holder models
    [deckel.stl, jahresschilder.stl, knopfvarianten.stl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]
2026-06-24 guide to place layer on object according to mapped led
